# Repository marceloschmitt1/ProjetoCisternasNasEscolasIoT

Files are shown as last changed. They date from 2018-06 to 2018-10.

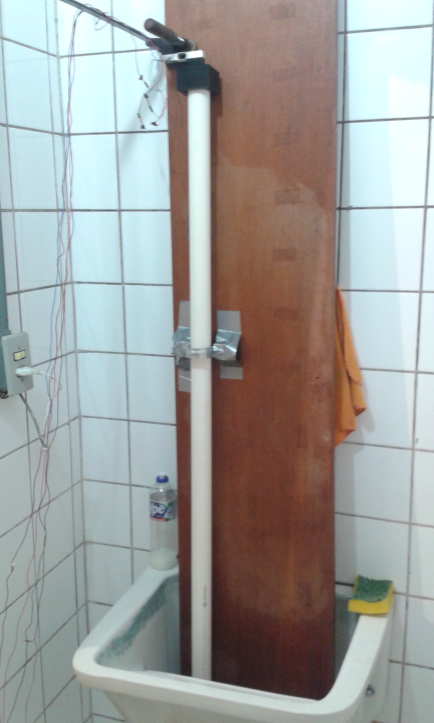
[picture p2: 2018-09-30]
SensorDeForca/sistema_medicao_teste.jpg

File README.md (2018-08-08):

# Cisternas nas Escolas IoT

Aplicação de Internet das coisas (IoT) na melhoria do Projeto Cisternas nas Escolas

## Projeto Cisternas nas Escolas
A ação Cisternas nas Escolas tem como objetivo construir sistemas de captação de água de chuva em escolas da rede pública de São Paulo e realizar atividades educacionais com base no projeto de engenharia para desenvolver habilidades de correlação e raciocínio lógico.

Em 2017, foram implementados 2 projetos técnico-educacionais de captação de água de chuva, na Escola Municipal de Ensino Fundamental Olavo Pezzotti e na Escola Municipal de Ensino Infantil Alberto de Oliveira. A iniciativa foi contemplada pelo edital da Associação Amigos da Poli, que financiou ambos os projetos ao longo do ano.

## Cisternas nas Escolas IoT - Descrição 

O projeto visa medir o volume de água em cisternas que captam água da chuva em escolas públicas de São Paulo.
A primeira escola onde o projeto deve ser implantando é a escola EMEF Olavo Pezotti que fica na Rua Fradique Coutinho, 2200.
A informação de nível da cisterna deve ser enviada a um servidor web e estar acessível somente para a gerência da escola.
Periodicamente as moças da limpeza tem que adicionar cloro na cisterna, mas muitas vezes elas esquecem de fazer isso e acumula uma espécie de musgo no interior da cisterna. Como complemento ao sensor de nível de água seria colocado um pequeno recipiente dentro da cisterna que jogasse pastilhas de cloro periodicamente na cisterna.

Público alvo: 
- Gerência das escolas, para gerenciar o uso da água
- Alunos, podem desenvolver interesse por ciência e engenharia a partir de projetos como esse
- Governo do estado de Sâo Paulo, pode monitorar o uso de recursos hídricos que as escolas fazem

## Cisternas nas Escolas IoT - Descrição técnica

Sensores: Quais sensores serão utilizados, onde eles poderão ser instalados, e a razão dessas escolhas.

Descrição técnica dos sensores: Apresentar os dados técnicos incluindo as características apresentadas no curso.

## Cisternas nas Escolas IoT - Descrição da arquitetura

Os dados serão coletados por um sensor acoplado à cisterna e transmitidos por um dispositivo IoT para a plataforma PubNub (https://www.pubnub.com) que fará a distribuição dos dados obtidos para os diversos dispositivos interessados (servidor de banco de dados da aplicação, usuários da interface gráfica do servidor, etc.). Após armazenados os dados no banco de dados eles estarão disponíveis para uso em predições de volume de água na cisterna, avaliação do histórico de uso, e outras aplicações. Com base nessas informações um usuário com permições de diretor / gestor poderá intervir na atividade da cisterna solicitando que seja despejada uma quantidade de cloro para limpeza da água coletada. Outras informações como previsão meteorológica também poderão ser incluídas na tomada de decisão de como melhor utilizar a água.

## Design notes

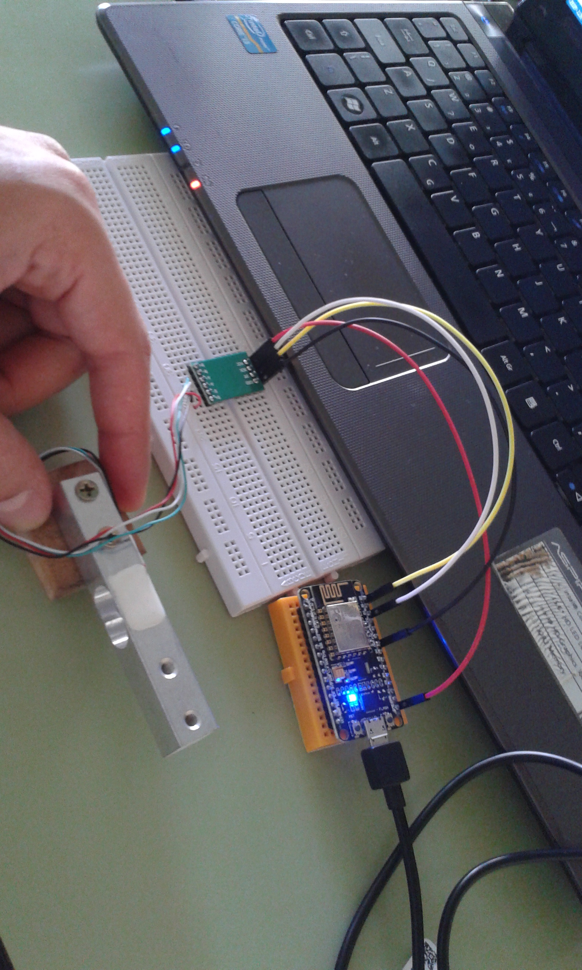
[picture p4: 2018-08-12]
SensorDeForca/NodeMCU_CelulaDeCarga/NodeMCU_celula_carga_foto.jpg

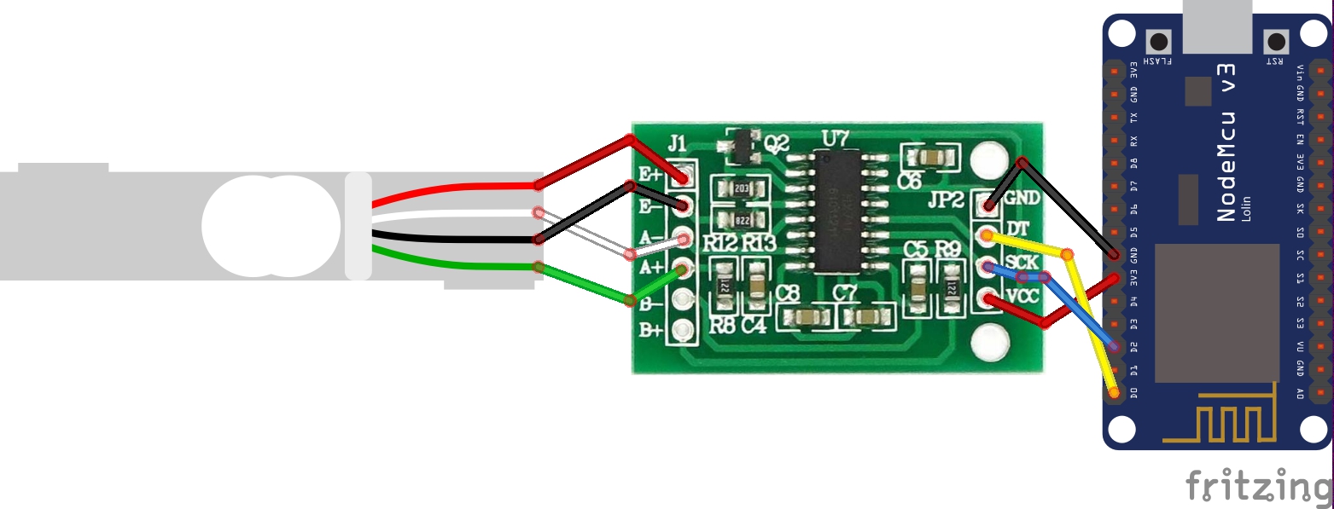
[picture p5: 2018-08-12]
SensorDeForca/NodeMCU_CelulaDeCarga/NodeMCU_celula_carga_esquematico.jpg

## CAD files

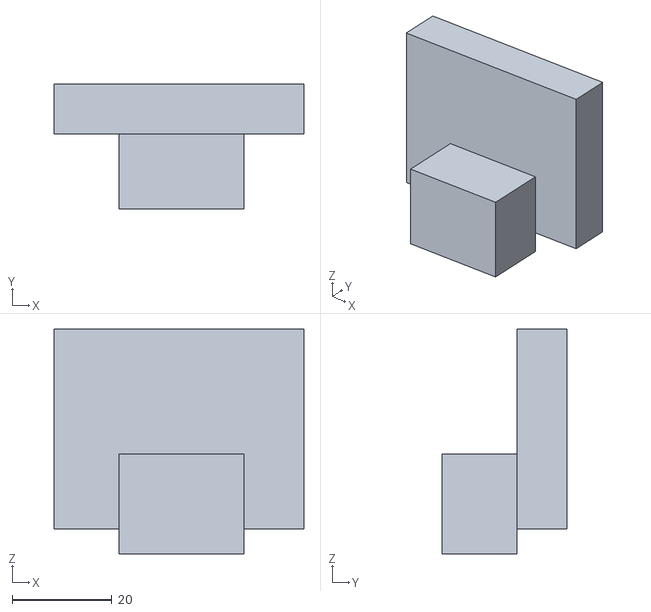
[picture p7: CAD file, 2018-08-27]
SensorDeForca/3D/FixadorSensorCisterna.stl
50.0 x 25.0 x 45.0

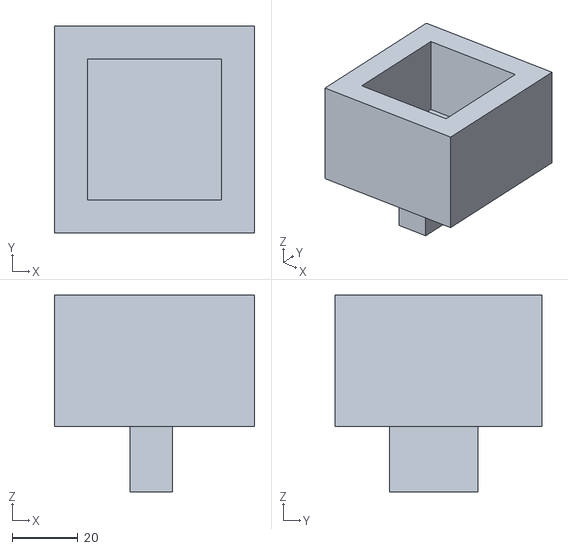
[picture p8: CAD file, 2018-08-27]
SensorDeForca/3D/Adaptador Cisterna.stl
61.0 x 63.0 x 60.0

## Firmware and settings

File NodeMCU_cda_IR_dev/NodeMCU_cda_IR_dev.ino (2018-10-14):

/*
  @author: Marcelo Schmitt

  https://github.com/deusanyjunior
  https://github.com/deusanyjunior/interscityroom8/blob/master/HTTPPostRequest.ino
*/
  
#include <SPI.h>
#include <ESP8266WiFi.h>

#include <ESP8266HTTPClient.h>
#include <WiFiUdp.h>
#include <time.h>

#include <ArduinoJson.h>

#define DEBUG
/* 
 * TODO
 * Sometimes PubNubDefs.h throws a "Connection reset in bottom half"
 * publishing a message to PubNub
 */
//#define VERBOSE 

#ifdef DEBUG
    #define D(X) X
    #ifdef VERBOSE
        #define PUBNUB_DEBUG
        #define V(X) X
    #else
        #define V(X)
    #endif
#else
    #define D(X)
    #define V(X)
#endif

//////////////////Propriedades Wireless////////////////////////////
const char* ssid = "rede_Mar";
const char* pass = "34753475";
///////////////////////////////////////////////////////////////////

////////////////Propriedades do PubNub/////////////////////////////
#define PubNub_BASE_CLIENT WiFiClient
#include <PubNub.h>

const static char pubkey[] = "pub-c-6ce39655-3209-4cea-acc9-543751fe4e55";
const static char subkey[] = "sub-c-6e52b6c2-8e6b-11e8-b7a4-ce74daf54d52";
const static char canal_de_dados[] = "dados_cisterna1";
const static char canal_de_comandos[] = "comando_cisterna1";
///////////////////////////////////////////////////////////////////

/////////////////Recursos NTP//////////////////////////////////////
unsigned int localPort = 2390;      // local port to listen for UDP packets
IPAddress timeServerIP; // time.nist.gov NTP server address //0.br.pool.ntp.org
const char* ntpServerName = "0.br.pool.ntp.org";
const int NTP_PACKET_SIZE = 48; // NTP time stamp is in the first 48 bytes of the message
byte packetBuffer[NTP_PACKET_SIZE]; //buffer to hold incoming and outgoing packets

// A UDP instance to let us send and receive packets over UDP
WiFiUDP udp;

// A time instance
time_t rawTime;
time_t startTime;
time_t now;
struct tm ts;
char timeBuffer[80];
bool timeDefined = false;
///////////////////////////////////////////////////////////////////


/////////////////Propriedades do sensor sharp//////////////////////
#define SHARP_PIN A0 // Pino do sensor infravermelho Sharp GP2Y0A21YK0F

//#define SHARP_HIGH 1.30
//#define SHARP_HIGH 1.70
#define SHARP_HIGH 0.58

//For Sharp GP2Y0A02YK0F
/*
#define INTERVALS 7
const float abscissas[] = {0.3, 0.35, 0.47, 0.57, 0.91, 1.48, 1.96, 2.47};
const float inclinacao[] = {-200, -166.67, -120, -117.64, -65.93, -20.83, -19.60};
const int ordenadas[] = {150, 140, 120, 100, 60, 40, 30, 20};
*/
// For Sharp GP2Y0A21YK0F
#define INTERVALS 8
const float abscissas[] = {0.34, 0.49, 0.62, 0.65, 0.83, 0.97, 1.29, 1.59, 2.38};
const float inclinacao[] = {-140, -100, -70, -55.55, -35.71, -15.62, -16.67, -6.32};
const int ordenadas[] = {83, 62, 49, 40, 30, 25, 20, 15, 10};
//83 0.34
//62 0.49
//54 0.54
//49 0.62
//43 0.69
//40 0.65
//30 0.83
//25 0.97
//20 1.29 ou 1.31
//15 1.59
//10 2.38

//80 0.45 ou 0.33
//73 0.5 ou outra coisa
//61 0.59
//
///////////////////////////////////////////////////////////////////


//peso do cano de casa: 113g

/////////////////Constantes da cisterna////////////////////////////
// Dados da cisterna na Amorim Lima
//Capacidade: 2500 L = 2.5 m^3
//Altura: 172 cm = 1.72 m
//Diâmetro: 157 cm
//Área da base * Altura = Capacidade => Área da base = 2.5/1.72 = 1.4534 m^2

//caixa da água
//https://www.fortlev.com.br/produto/caixa-dagua-de-polietileno-2/
//Capacidade - litros
//A - Altura com tampa
//B - Altura sem tampa
//C - Diâmetro com tampa
//D - Diâmetro sem tampa
//E - Diâmetro da base
//500   0,72  0,58  1,24  1,22  0,95
//Altura sem tampa 0.58m
//Diamtro da base 0.95m


//numero identificador da cisterna
#define ID_CISTERNA 1

//altura em metros: 1.72 m = 172 cm
#define CISTERNA_HIGH 0.54m
//area da base da cisterna (em metros quadrados)
#define CISTERNA_BASE_AREA 0.7089

//capacidade da cisterna (em metros cubicos)
#define CISTERNA_CAPACITY 0.411104544

//distancia do sensor ateh o nivel do ladrao (em metros)
//#define OFFSET 0.3

///////////////////////////////////////////////////////////////////


#define ACTUATOR_PIN D6

//long inicio = millis();

void setup() {
    Serial.begin(115200);
    //D(Serial.println("Iniciando celula de carga ...");)

    pinMode(SHARP_PIN, INPUT);
    
    pinMode(ACTUATOR_PIN, OUTPUT);
  
//    pwm.setup(ACTUATOR_PIN, 100, 512);
    
    D(Serial.println("Attempting to connect to WPA network...");)
    wifiConnection();
    
    udp.begin(localPort);
    
    PubNub.begin(pubkey, subkey);
    
}

void loop() {

    //if (false) {
    if (WiFi.status() != WL_CONNECTED) {
        wifiConnection();
    } else {
        float voltage = read_sharp();
        float distance = calculate_distance(voltage);
        D(Serial.print("distance: ");)
        D(Serial.println(distance);)
        if (!distance) {
            delay(500);
            return;
        }
        
        // O volume de agua eh o volume total menos a distancia do sensor ateh a superficie da agua.
        //float litros = (CISTERNA_CAPACITY - ((CISTERNA_HIGH - distance) * CISTERNA_BASE_AREA))*1000; // volume de agua em litros
        float litros = ((SHARP_HIGH - distance) * CISTERNA_BASE_AREA)*1000; // volume de agua em litros
        //float litros = voltage;
        D(Serial.print("litros: ");)
        D(Serial.println(litros);)
        //litros = litros > 0 ? litros : 0;

        
        // Get current time from NTP
        if (!timeDefined) {
          if (!getTimeNTP()) return; // Get time from NTP servers
          timeDefined = true;
        }
        // set current time based on statup time
        time (&rawTime);
        now = rawTime + startTime;
        ts = *localtime(&now);
        strftime(timeBuffer, sizeof(timeBuffer), "%Y-%m-%dT%H:%M:%S", &ts);

        D(Serial.println(timeBuffer);)
        String json_string = "{\"cisterna\":" + String(ID_CISTERNA) + "," + "\"time_stamp\":\"" + String(timeBuffer) + "\"," + "\"eon\":{\"litros\":" + String(litros) + "}}";
        
        publishToPubNub(json_string);
        
        //checkPubNubHistory();
        
    }
    //delay(3000);  
    delay(60000);
}

// Method to (re)connect to WiFi network
void wifiConnection() {
    D(Serial.print("Connecting to ");)
    D(Serial.println(ssid);)
    WiFi.mode(WIFI_STA);
    WiFi.begin(ssid, pass);
    while (WiFi.status() != WL_CONNECTED) {
      delay(500);
      D(Serial.print(".");)
    }
    D(Serial.println("");)
    D(Serial.println("WiFi connected");)
    D(Serial.print("Endereco IP: ");)
    D(Serial.println(WiFi.localIP());)
}

/*
 * Tira 9 medidas do sensor e toma a mediana para obter um valor 
 * mais confiável.
 */
float read_sharp() {
    D(Serial.println("Leitura do sensor sharp: ");)
    int sharp_readings[9];
    for (int i = 0; i < 9; i++) {
        sharp_readings[i] = 10000; // O certo seria usar INT_MAX no lugar de 10000
        int sharp_reading = analogRead(SHARP_PIN);
        V(Serial.println(sharp_reading);)
        int j = 0;
        while (sharp_readings[j] < sharp_reading) j++;
        for (int k = i;k > j; k--) sharp_readings[k] = sharp_readings[k-1];
        sharp_readings[j] = sharp_reading;
        delay(200);
    }
    D(Serial.print("sharp_readings median: ");)
    D(Serial.println(sharp_readings[4]);)
    float sensor_voltage = (1.0*sharp_readings[4]/1024) * 3.0;
    D(Serial.print("voltage: ");)
    D(Serial.println(sensor_voltage);)
    return sensor_voltage;
}

/*
 * Calcula e retora a distancia em metros
 */
float calculate_distance(float voltage) {
    // Leitura incorreta
    if (voltage < abscissas[0] || voltage > abscissas[INTERVALS]) {
        D(Serial.print("bad sensor reading: ");)
        D(Serial.println(voltage);)
        return 0;
    }
    int i;
    for (i = 1; i < INTERVALS; i++) 
        if (voltage < abscissas[i]) break;
//    D(Serial.print(ordenadas[i]);)
//    D(Serial.print(" + ");)
//    D(Serial.print(inclinacao[i]);)
//    D(Serial.print("*(");)
//    D(Serial.print(leitura);)
//    D(Serial.print(" - ");)
//    D(Serial.print(abscissas[i]);)
//    D(Serial.print(")");)
//    D(Serial.println();)
    //float distancia = ordenadas[i] + inclinacao[i]*(voltage - abscissas[i]); //em centimetros
    
    float distance = ordenadas[i] + inclinacao[i-1]*(voltage - abscissas[i]);
    //D(Serial.print("calculated distance: ");)
    //D(Serial.println(distance);)
    return distance / 100;
}

void publishToPubNub(String json_string) {
    V(Serial.println("PublishToPubNub");)
    char json_char_array[100];
    json_string.toCharArray(json_char_array, 100);
    D(Serial.println(json_char_array);)
    V(Serial.println("Publishing to PubNub ...");)
    WiFiClient *client;
    client = PubNub.publish(canal_de_dados, json_char_array);
    delay(1500);
    if (!client) {
        Serial.println("publishing error at sketch");
        delay(1000);
        return;
    }
    if (PubNub.get_last_http_status_code_class() != PubNub::http_scc_success) {
        Serial.print("Got HTTP status code error from PubNub, class: ");
        Serial.print(PubNub.get_last_http_status_code_class(), DEC);
    }
    V(Serial.println("Publich responce");)
    V(while (client->available()) {)
        V(Serial.write(client->read());)
    V(})
    V(Serial.println();)
    client->stop();
}


void checkPubNubHistory() {
    V(Serial.println("Retrieving message history");)
    WiFiClient *client;
    client = PubNub.history(canal_de_comandos, 1);
    if (!client) {
        Serial.println("PubNub history error");
        return;
    }
    String command_json = "";
    while (client->connected()) {
        while (client->connected() && !client->available()) ; // wait
        char c = client->read();
        command_json += c;
    }
    client->stop();
    V(Serial.print("command_json: ");)
    V(Serial.print(command_json);)
    V(Serial.println();)
    command_json.replace("[", "");
    command_json.replace("]", "");
    StaticJsonBuffer<200> jsonBuffer;
    JsonObject& root = jsonBuffer.parseObject(command_json);
    if (!root.success()) {
      D(Serial.println("parseObject() failed");)
    }
    const char* command = root["comando"];
    if (String(command).equals("ativa")) {
        analogWrite(ACTUATOR_PIN, 800);
    } else if (String(command).equals("desativa")) {
        analogWrite(ACTUATOR_PIN, 100);
    }
}


// Method to get the NTP response and backup the *startTime*
bool getTimeNTP() {
    Serial.println("Get time from NTP servers");
    //get a random server from the pool
    WiFi.hostByName(ntpServerName, timeServerIP);
  
    sendNTPpacket(timeServerIP); // send an NTP packet to a time server
    // wait to see if a reply is available
    delay(1000);
  
    int cb = udp.parsePacket();
    if (!cb) {
        Serial.println("no NTP packet yet");
        delay(10000);
        return false;
    } else {
        Serial.print("NTP packet received, length=");
        Serial.println(cb);
        // We've received a packet, read the data from it
        udp.read(packetBuffer, NTP_PACKET_SIZE); // read the packet into the buffer
    
        //the timestamp starts at byte 40 of the received packet and is four bytes,
        // or two words, long. First, esxtract the two words:
        unsigned long highWord = word(packetBuffer[40], packetBuffer[41]);
        unsigned long lowWord = word(packetBuffer[42], packetBuffer[43]);
    
        // combine the four bytes (two words) into a long integer
        // this is NTP time (seconds since Jan 1 1900):
        unsigned long secsSince1900 = highWord << 16 | lowWord;
    
        // now convert NTP time into everyday time:
        // Unix time starts on Jan 1 1970. In seconds, that's 2208988800:
        const unsigned long seventyYears = 2208988800UL;
    
        // subtract seventy years:
        //unsigned long epoch = secsSince1900 - seventyYears;

        //subtarct 3 hours to match São Paulo - Brazil timezone
        const long timeZoneOffset = -10800L; //3 hours in seconds
        now = secsSince1900 - seventyYears + timeZoneOffset ;
        
        // backup time after seventy years
        time( &rawTime );
        startTime = now - rawTime;
    
        Serial.println("Time defined");
    
        return true;
    }
}

// Method to send an NTP request to the time server at the given address
unsigned long sendNTPpacket(IPAddress& address) {
    Serial.println("sending NTP packet...");
    // set all bytes in the buffer to 0
    memset(packetBuffer, 0, NTP_PACKET_SIZE);
    // Initialize values needed to form NTP request
    // (see URL above for details on the packets)
    packetBuffer[0] = 0b11100011;   // LI, Version, Mode
    packetBuffer[1] = 0;     // Stratum, or type of clock
    packetBuffer[2] = 6;     // Polling Interval
    packetBuffer[3] = 0xEC;  // Peer Clock Precision
    // 8 bytes of zero for Root Delay & Root Dispersion
    packetBuffer[12]  = 49;
    packetBuffer[13]  = 0x4E;
    packetBuffer[14]  = 49;
    packetBuffer[15]  = 52;
  
    // all NTP fields have been given values, now
    // you can send a packet requesting a timestamp:
    udp.beginPacket(address, 123); //NTP requests are to port 123
    udp.write(packetBuffer, NTP_PACKET_SIZE);
    udp.endPacket();
}

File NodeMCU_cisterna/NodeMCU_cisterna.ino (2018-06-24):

/*
  @author: Marcelo Schmitt
*/
  
#include <SPI.h>
#include <ESP8266WiFi.h>

#define DEBUG

#ifdef DEBUG
    #define D(X) X
//    #define PUBNUB_DEBUG
#else
    #define D(X)
#endif

#define PubNub_BASE_CLIENT WiFiClient
#include <PubNub.h>

#define SERVO_PIN D6
#define SHARP_PIN A0

#include <ArduinoJson.h>

int status = WL_IDLE_STATUS;                // the Wifi radio's status

// Wireless settings
const char* ssid = "MarDroid";
const char* pass = "mirtero1";

// PubNub settings
const static char pubkey[] = "pub-c-3ef4941c-5a95-497a-b7bf-ed6d0823b186";         // your publish key 
const static char subkey[] = "sub-c-cd8b8d8e-6941-11e8-98cb-067913ebee63";         // your subscribe key
//const static char channel[] = "cisterna"; // channel to use
const static char dados_channel[] = "dados_cisterna"; // channel to use
const static char comando_channel[] = "comando_cisterna"; 

// Constantes de calibracao e mensuracao
#define INTERVALOS 6
const float abscissas[] = {0.3, 0.35, 0.47, 0.57, 1.48, 1.96, 2.47};
const float inclinacao[] = {-200, -166,67, -200, -65,93, -20,83, -19,60};
const int ordenadas[] = {150, 140, 120, 100, 40, 30, 20};

long inicio = millis();

void setup() {
  //pinMode(SHARP_PIN, INPUT);
  pinMode(SERVO_PIN, OUTPUT);

//  pwm.setup(SERVO_PIN, 100, 512);
  
  Serial.begin(115200);
  D(Serial.println("Serial set up");)

  // attempt to connect using WPA2 encryption:
  D(Serial.println("Attempting to connect to WPA network...");)

  wifiConnection();

  PubNub.begin(pubkey, subkey);
}

bool par = true;

void loop() {

    if (WiFi.status() != WL_CONNECTED) {
        wifiConnection();
    } else {
        //Leitura do sensor
        int leitura_analogica = analogRead(SHARP_PIN);
//        float voltagem_sensor = (1.0*analogRead(SHARP_PIN)/1024) * 5; //Conversão com Arduino
        float voltagem_sensor = (1.0*leitura_analogica/1024) * 3.0;
        
        //Se a voltagem medida pelo sensor for menor que 0.4V ~ 130cm 
        //então a leitura está errada pois da base até o topo da cisterna 
        //há apenas 130cm de altura.
        if (voltagem_sensor < 0.4) {
            //leitura inconsistente
            Serial.println("leitura maior que 130cm");
            delay(1000);
            return;
        }
        
        //Se a voltagem medida pelo snsor for maior que 2.5V ~ 20cm 
        //então a leitura está errada pois a água dentro da cisterna 
        //deve chegar a no máximo 110cm de altura (no máximo a 20cm 
        //de distância de sensor).
        if (voltagem_sensor > 2.5) { //TODO fazer um #define calcular os filtros com base na distancia
            //leitura inconsistente
            Serial.println("leitura menor que 20cm");
            delay(1000);
            return;
        }

        D(Serial.print("leitura_analogica: ");)
        D(Serial.print(leitura_analogica);)
        D(Serial.print(" voltagem_sensor: ");)
        D(Serial.print(voltagem_sensor);)
        float distancia = calcula_distancia(voltagem_sensor);
        D(Serial.print(" distancia: ");)
        D(Serial.println(distancia);)

        //Time stamp provisorio
//        String str_dist = "[{\"tempo\":\"" + String((1.0*millis()-inicio)/1000) + "\"}," + "{\"distancia\":" + String(distancia) + "}]";
//        String str_dist = "{\"eon\":[{\"tempo\":\"" + String((1.0*millis()-inicio)/1000) + "\"}," + "{\"distancia\":" + String(distancia) + "}]}";

        String str_dist = "{\"eon\":{\"tempo\":" + String((1.0*millis()-inicio)/1000) + "," + "\"distancia\":" + String(distancia) + "}}";

        char msg[100];
        str_dist.toCharArray(msg, 100);
        Serial.println(msg);
        
        //Envio da mensagem para a nuvem (usando o servico do PubNub)
        WiFiClient *client;        
        client = PubNub.publish(dados_channel, msg);
        if (!client) {
            Serial.println("publishing error");
            delay(1000);
            return;
        }
        if (PubNub.get_last_http_status_code_class() != PubNub::http_scc_success) {
            Serial.print("Got HTTP status code error from PubNub, class: ");
            Serial.print(PubNub.get_last_http_status_code_class(), DEC);
        }
//        while (client->available()) {
//            D(Serial.write(client->read());)
//        }
        client->stop();
//        Serial.println("---");

        Serial.println();
        
        // Parte de controle da cistenar (despejo de produto de limpeza)
        String ordem = "";
        
//        Serial.println("retrieving message history");
        client = PubNub.history(comando_channel, 1);
        if (!client) {
            Serial.println("history error");
            delay(1000);
            return;
        }
        while (client->connected()) {
            while (client->connected() && !client->available()) ; // wait
            char c = client->read();
            ordem += c;
//            Serial.print(c);
        }
//        Serial.print("ordem: ");
//        Serial.print(ordem);
        client->stop();
//        Serial.println();

        ordem.replace("[", "");
        ordem.replace("]", "");
//        Serial.print("ordem: ");
//        Serial.print(ordem);
//        Serial.println();

        StaticJsonBuffer<200> jsonBuffer;
        JsonObject& root = jsonBuffer.parseObject(ordem);
        if (!root.success()) {
          Serial.println("parseObject() failed");
        }
        const char* comando = root["comando"];
//        Serial.print("comando: ");
//        Serial.print(comando);
//        Serial.println();

        if (String(comando).equals("ativa")) {
            analogWrite(SERVO_PIN, 800);
        } else if (String(comando).equals("desativa")) {
            analogWrite(SERVO_PIN, 100);
        }
        
    }
    delay(1000);
  
}

float calcula_distancia(float leitura) {
    int i;
    for (i = 0; i < INTERVALOS+1; i++) 
        if (leitura < abscissas[i]) break;

//    D(Serial.print(ordenadas[i]);)
//    D(Serial.print(" + ");)
//    D(Serial.print(inclinacao[i]);)
//    D(Serial.print("*(");)
//    D(Serial.print(leitura);)
//    D(Serial.print(" - ");)
//    D(Serial.print(abscissas[i]);)
//    D(Serial.print(")");)
//    D(Serial.println();)
    float distancia = ordenadas[i] + inclinacao[i]*(leitura - abscissas[i]);
    return distancia;  
}

// Method to (re)connect to WiFi network
void wifiConnection() {
    D(Serial.print("Connecting to ");)
    D(Serial.println(ssid);)
    WiFi.mode(WIFI_STA);
    WiFi.begin(ssid, pass);
    while (WiFi.status() != WL_CONNECTED) {
      delay(500);
      D(Serial.print(".");)
    }
    D(Serial.println("");)
    D(Serial.println("WiFi connected");)
    D(Serial.print("IP address: ");)
    D(Serial.println(WiFi.localIP());)
}

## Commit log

2018-04-05 Outra ideia de projeto
2018-05-30 PubNubNodeMCU_demo
    Sketch de exemplo de uso do PubNub com o NodeMCU
2018-06-19 Abordagem Sensor Capacitivo
2018-06-19 Abordagem NodeMCU sensor IR
    Sketch NodeMCU usando infravermelho e motor servo. Arquivos python para regressão linear dos dados.
2018-06-20 Criado servidor django
    Criação de um servidor django para manter as páginas de visualização dos dados da cisterna e também para o envio de comandos a atuadores.
2018-08-03 Esboço de site
    Fiz um app django para o site das cisternas. Criei um sketch NodeMCU_cisterna_dev em que fiz pequenos ajustes de nomenclatura nos campos dos arquivos json enviados para o pubnub. Instalei uma API RES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
2018-08-08 Ajuste para deploy no pythonanywhere
    Pequeno ajuste na classe MedicaoSerializer. Ajuste para utilizar o sqlite3 pois pythonanywhere free não suporta postgres. Inclusão de um arquivo com alguns comandos úteis que tenho utilizado para faz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
2018-08-09 Ajustes de configuração e pubnub function
    Pequeno ajuste de configuração para permitir o acesso às páginas quando hosteadas no pythonanywhere. Alguns comentários e testes nos arquivos cisternas/views.py e cisternas/urls.py. Copiei o código d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
2018-08-10 Melhorando as api views
    Uma versão intermediária da melhoria das api views segundo o tutorial do Django REST framework.
2018-08-10 Melhorando as api views
    Versão de api view Class-based sem mixins. Tuturial Django REST framework parte 3.
2018-08-12 Teste com célula de carga
    Sketch para teste de célula de carga em conjunto com placas NodeMCU. Testado com uma célula de carga de 1Kg de capacidade e um amplificador hx711. Parece funcionar bem. =)
    [NodeMCU_celula_carga_fritzing.fzz]
2018-08-14 Sketch Arduino envia timestampo correto
    Peguei emprestado duas funções do dj que fazem uma requisião NTP para obter o timestamp atual e transmití-lo junto como a medição de volume de água da cisterna. Refatorei um pouco o Sketch Arduino. C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
2018-08-16 Melhoria das telas do site
    Coloquei a contegem correta de cisternas e medições na página principal. Refatorei a página de detalhes da cisterna e incluí um gauge chart nela.
2018-08-20 Plano de uso do sensor
    Plano de como utilizar o sensor de força / célula de carga para medir o volume de água da cisterna.
    [NodeMCU_celula_carga_fritzing.fzz]
2018-08-24 Correção para obter timestamp correto
    Incluí uma linha para iniciar a comunicação UDP que estava faltando e fiz uma alteração para colocar o timestamp otido do servidor NTP no fuso horário de brasília.
2018-08-24 Melhoria da interface
    Arrumei o label de valor do gauge. Associei as informação da página de listagem de cisternas com os dados reais que estão no BD.
2018-08-24 Mudança no modelo, na view, e authetication
    Muitas coisas que eu deveria ter feito em commits menores. 1º adicionei configuração para usar o sistema de autenticação do django_rest para acesso à api REST. 2º Mudei o modelo (classe) Cisterna adi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
2018-08-27 Calibração do sensor e modelos 3D
    Ajuste do fator_de_calibração para que a célula de carga informe medidas força em gramas. Modelos 3D dos adaptadores feitos para a célula de carga (um para acoplar o cano à ponta do sensor e outro para fixar o sensor na parede da cisterna).
    [Adaptador Cisterna.stl, FixadorSensorCisterna.stl]
2018-09-18 Calculo do volume de água
    Ajustei o sketch arduino para calcular o volume de água considerando as medidas reais da cistena na EMEF Olavo Pezzotti
2018-09-30 Mudança de célula de carga para sharp
    Adicinando últimas coisas feitas com célula de carga. Mudança do sketch de desenvolvimento para usar o sharp.
2018-09-30 Configuração para testes
2018-10-03 Sketch agora usa sensor Sharp
    Modifiquei o sketch para usar o sensor SharpGP2Y0A02Y. Pequenos ajustes na interface web.
2018-10-14 Sketch para caixa d'água e fotos sharp
    Inclui sketch utilizado na medição de volume de água da caixa da água de minha casa. Inclúi fotos relacionadas ao sensor Sharp.
